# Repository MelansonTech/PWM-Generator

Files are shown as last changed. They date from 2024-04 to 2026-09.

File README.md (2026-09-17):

# PWM Generator

A low-cost, adjustable PWM signal generator built around an LM393 dual comparator.
One half of the comparator runs a sawtooth oscillator, the other slices it against an
adjustable threshold, and a discrete push-pull follower drives the output to 100 mA.

No microcontroller, no firmware — two trimmers and a jumper.

Complete CircuitStudio design: schematic, PCB, and a released manufacturing package
(Gerbers, NC drill, pick & place, BOM, STEP).

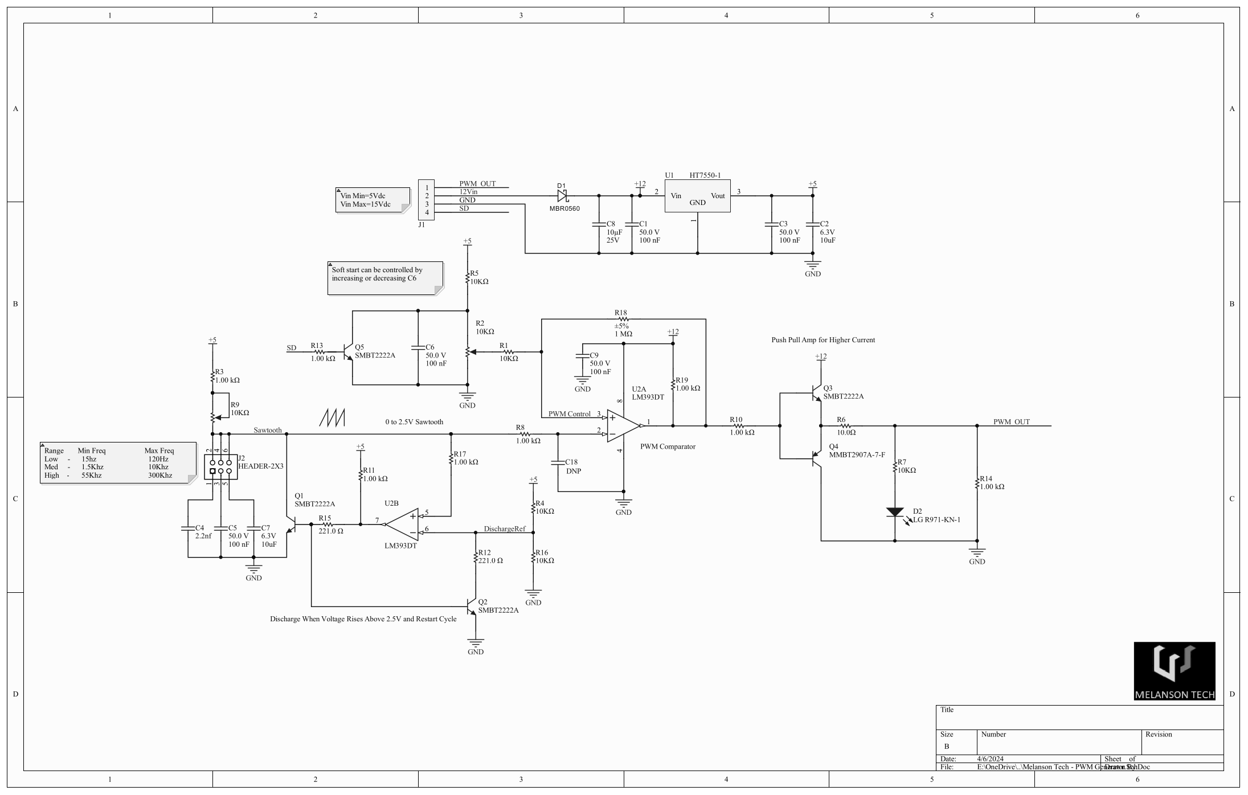
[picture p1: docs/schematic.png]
Schematic of the LM393 PWM generator


<sub>Full-size schematic, PCB drawings and 3D views:
[`PWM Generator Rev 1.PDF`](Default%20Configuration/Outputs/PWM%20Generator%20Rev%201.PDF)</sub>

---

## Specifications

| | |
|---|---|
| Supply voltage | 5 – 15 V DC |
| Output current | up to 100 mA |
| Output swing | GND to the input rail, less the input diode drop and one V<sub>BE</sub> |
| Duty cycle | 0 – 100 %, set by trimmer R2 |
| Frequency | 15 Hz – 300 kHz across three jumper-selected ranges |
| Soft start | duty ramps up from zero on power-up (C6) |
| Shutdown | active-high SD input forces 0 % duty |
| Board | 25.0 × 28.0 mm (0.98 × 1.10 in), 2-layer |
| Assembly | SMD on the bottom side only, plus 4 through-hole parts |
| Placements | 40 (19 unique parts, C18 not populated) |

## Frequency ranges

Range is selected by jumpering one pair on **J2**, which switches the oscillator's
timing capacitor:

| J2 jumper | Timing cap | Range |
|---|---|---|
| 1 – 2 | C4, 2.2 nF | 55 kHz – 300 kHz |
| 3 – 4 | C5, 100 nF | 1.5 kHz – 10 kHz |
| 5 – 6 | C7, 10 µF | 15 Hz – 120 Hz |

Within a range, **R9** sets the frequency. Exactly one pair should be jumpered at a time.

## Connections

**J1** — 1×4, 0.1 in pitch:

| Pin | Net | Description |
|---|---|---|
| 1 | `PWM_OUT` | PWM output, up to 100 mA |
| 2 | `Vin` | 5 – 15 V DC supply |
| 3 | `GND` | Ground |
| 4 | `SD` | Shutdown, active high — forces 0 % duty. Leave open or tie to GND for normal operation |

## Adjustments

| Part | Function |
|---|---|
| R9 | Frequency, within the range selected by J2 |
| R2 | Duty cycle |
| C6 | Soft-start time constant — increase for a slower ramp, decrease for a faster one |

Both are 10 kΩ top-adjust trimmers (CT94EW103).

## How it works

- **Input** — Vin enters through D1 (MBR0560 Schottky) for reverse-polarity protection.
  U1, an HT7550-1 SOT-89 LDO, derives the +5 V rail that the comparator and timing
  network run from. The output stage runs from the input rail, not the 5 V rail, so the
  PWM output swings as high as the supply allows.
- **Sawtooth oscillator** — One half of U2 (LM393) charges the selected timing capacitor
  through R9 and discharges it at a fixed reference, producing a 0 – 2.5 V sawtooth.
  J2 picks the capacitor and therefore the range; R9 sets the charge current and
  therefore the frequency.
- **PWM comparator** — The other half of U2 compares the sawtooth against a DC control
  voltage from R2. Where the control voltage sits within the sawtooth's 0 – 2.5 V span
  is the duty cycle.
- **Soft start** — C6 sits on the control node and charges through R5 at power-up, so
  the control voltage ramps from 0 V and the duty cycle ramps with it.
- **Shutdown** — Driving SD high turns on Q5, which pulls the control node to ground and
  holds the output at 0 % duty.
- **Output stage** — Q3 (NPN, SMBT2222A) and Q4 (PNP, MMBT2907A) form a complementary
  emitter follower. R6 (10 Ω) is in series with the output and R14 (1 kΩ) pulls it down.
- **Indicator** — D2, a green LED, sits across the output through R7 (10 kΩ), so its
  brightness follows the duty cycle.

Key parts: **U2** LM393DT · **U1** HT7550-1 · **Q1–Q3, Q5** SMBT2222A · **Q4** MMBT2907A-7-F · **D1** MBR0560

## Repository layout

```
Melanson Tech - PWM Generator.PrjPcb      CircuitStudio project
Melanson Tech - PWM Generator.SchDoc      Schematic
Melanson Tech - PWM Generator.CSPcbDoc    PCB layout
PWM Generator Rev 1.OutJob                Output job - regenerates everything below

docs/schematic.png                        Schematic image used above

Default Configuration/Outputs/
  PWM Generator Rev 1.PDF                 Schematic and PCB drawings
  Gerber/                                 RS-274X, 2 layers, bottom-side assembly
  NC Drill/                               Excellon drill files and drill report
  Pick Place/                             Placement data, .csv and .txt
  BOM/                                    Bill of materials with Digi-Key part numbers
  ExportSTEP/                             3D model of the assembled board
```

## Opening the design

Open `Melanson Tech - PWM Generator.PrjPcb` in Altium CircuitStudio (the outputs here
were generated with 1.5.2) or in Altium Designer, which reads the same formats.

The project's library search path points at a local folder, so schematic symbols and
footprints may not resolve on another machine. The design files themselves carry
everything needed to view, plot, and fabricate the board — the libraries are only
required to edit components or re-run an ECO.

## Ordering boards

The manufacturing package under `Default Configuration/Outputs/` was generated on
2024-04-06 and is what you send to a fab house:

- **Gerbers** — RS-274X, metric, 2 layers (`.GTL` top copper, `.GBL` bottom copper),
  with `.Outline` as the board outline
- **Drill** — `.DRL` (Excellon) plus `.DRR`; 40 plated holes, 4 tools, smallest 0.3 mm
- **Assembly** — pick & place plus the `.GBP` bottom paste layer. Every SMD part is on
  the bottom side, so this is a single-sided reflow. J1, J2 and the two trimmers are
  through-hole.
- **BOM** — `BOM_PartType-Melanson Tech - PWM Generator.xls`, with Digi-Key part numbers
  for most line items. C18 is marked **DNP** — do not populate.

If you change the design, re-run `PWM Generator Rev 1.OutJob` rather than editing these
files by hand.

## License

**CERN Open Hardware Licence Version 2 — Strongly Reciprocal (`CERN-OHL-S-2.0`).**

Copyright © 2024–2026 MelansonTech (Shawn Melanson).

This source describes Open Hardware and is licensed under CERN-OHL-S v2. You may redistribute
and modify it under the terms of that licence. This source is distributed *WITHOUT ANY EXPRESS
OR IMPLIED WARRANTY, INCLUDING OF MERCHANTABILITY, SATISFACTORY QUALITY AND FITNESS FOR A
PARTICULAR PURPOSE.* Please see the licence for applicable conditions.

In short: you may build, modify and sell this design, but if you distribute a modified version —
or a product made from one — you must publish your modified source under the same licence.

The full licence text is in [`LICENSE`](LICENSE), or at <https://cern.ch/cern-ohl>.

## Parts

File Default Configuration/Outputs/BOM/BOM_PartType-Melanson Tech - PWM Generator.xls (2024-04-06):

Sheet: BOM Report
Bill of Materials |  |  | <Parameter Title not found>
Source Data From: |  | Melanson Tech - PWM Generator.PrjPcb
Project: |  | Melanson Tech - PWM Generator.PrjPcb
Variant: |  | None
Creation Date: | 4/5/2024 | 2:28:50 PM
Print Date: | 2024-04-06 | 10:28:01
Production Quantity: | 100
Currency | CAD
Footprint | Comment | LibRef | Designator | Description | Quantity | Supplier 1 | Supplier Part Number 1 | Supplier Unit Price 1 | Supplier Order Qty 1 | Supplier Subtotal 1 | Manufacturer 1 | Manufacturer Part Number 1
Cap,0805 | 08055C104JAT2A | Cap,0805,100nf,50V,5%,08055C104JAT2A | C1, C3, C5, C6, C9 | 100nf 0805 Capacitor | 5 | Digi-Key | 478-3352-1-ND |  |  |  | Loading... | Loading...
Cap,0805 | CL21A106KQFNNNG | Cap,0805,10uf,6.3V,10%,CL21A106KQFNNNG | C2, C7 | CL21 Series 10 uF 6.3V ±10 % Tolerance X5R SMT Multilayer Ceramic Capacitor | 2 | Digi-Key | 1276-6457-1-ND | 0.04235 | 200 | $8.47 | Samsung | CL21A106KQFNNNG
CAP, 0805, HD | 2.2nf | CAP,0805,Generic | C4 | 2.2nf 0805 Capacitor | 1
Cap, 1206 | C3216X7R1E106K160AB | CAP,1206,10uF,25V,C3216X7R1E106K160AB | C8 | 10µF ±10% 25V Ceramic Capacitor X7R 1206 (3216 Metric) | 1 | Digi-Key | 445-7705-1-ND |  |  |  | Loading... | Loading...
CAP, 0805, HD | GRM21A5C2E101JW01D | Cap,0805,100pf,250V,5%,GRM21A5C2E101JW01D | C18 | CAP CER 100PF 250V 5% NP0 0805 | DNP | Digi-Key | 490-5542-1-ND | 0.13403 | 100 | $13.40 | Murata | GRM21A5C2E101JW01D
SOD123 | MBR0560 | Diode,SOD123,Shottky,60V,0.5A,MBR0560 | D1 | Dio,Sig,Schtky,0.5A,60V,SOD123 | 1 | Digi-Key | MBR0560TPMSCT-ND | 0.11076 | 100 | $11.08 | MCC | MBR0560-TP
LED,0805 | LG R971-KN-1 | LED,0805, Green,SMD,LG R971-KN-1 | D2 | LED GREEN DIFFUSED 0805 SMD | 1 | Digi-Key | 475-1410-1-ND |  |  |  | Loading... | Loading...
Header,4POS,0.1",Vert | Generic Header | Header 1x4,0.1",TH,Generic | J1 | Generic Header 4 pos header 0.1" | 1
HEADER-2X3 | HEADER-2X3 | HEADER-2X3 | J2 | 'Generic Header 8 pos 2x3 0.1" | 1
SOT23-3 | SMBT2222A | Trans,40V,600mA,0.33W, SMBT2222A | Q1, Q2, Q3, Q5 | NPN Silicon Switching Transistor, 40 V VCEO, 600 mA IC, SOT23, Reel, Green | 4 | Digi-Key | SMBT2222AE6327HTSA1CT-ND | 0.14739 | 400 | $58.95 | Infineon | SMBT2222AE-6327
SOT23-3 | MMBT2907A-7-F | Trans,PNP,60Vdc,600mA,SOT-23-3,MMBT2907A-7-F | Q4 | TRANS PNP 60V 0.6A SOT23-3 | 1 | Digi-Key | MMBT2907A-FDICT-ND | 0.06854 | 100 | $6.85 | Diodes Zetex | MMBT2907A-7-F
res, 0805, HD | Vishay / Dale CRCW080510K0FKTA | Res,0805,10.0kO,1%,100 ppm,CRCW080510K0FKTA | R1, R4, R5, R7, R16 | RES SMD 10K OHM 1% 1/8W 0805 | 5 | Digi-Key | 541-3016-1-ND |  |  |  | Loading... | Loading...
Res,TH,POT,TopAdj | CT94EW103 | Res,POT,TH,10KO,0.5W,±10%,±100ppm/°C,CT94EW103 | R2, R9 | TRIMMER 10K OHM 0.5W PC PIN TOP | 2 | Digi-Key | CT94EW103-ND |  |  |  | Loading... | Loading...
res, 0805, HD | Vishay CRCW08051K00JNEA | Res,0805,1.00 kO,5%,200ppm,CRCW08051K00JNEA | R3, R8, R10, R11, R13, R14, R17, R19 | Res Thick Film 0805 1K Ohm 5% 0.125W(1/8W) ±200ppm/C Molded SMD Automotive Paper T/R | 8 | Digi-Key | 541-1.0KADKR-ND |  |  |  | Loading... | Loading...
res, 0805, HD | RMCF0805JT10R0 | Res,0805,10.0O,5%,±200ppm/°C,RMCF0805JT10R0 | R6 | RES 10 OHM 5% 1/8W 0805 | 1 | Digi-Key | RMCF0805JT10R0CT-ND | 0.01106 | 100 | $1.11 | Stackpole Electronics | RMCF0805JT10R0
res, 0805, HD | Vishay Dale CRCW0805221RFKTA | Res,0805,221O,1%,100ppm,CRCW0805221RFKTA | R12, R15 | RES SMD 221 OHM 1% 1/8W 0805 | 2 | Digi-Key | 541-221CCT-ND | 0.02671 | 200 | $5.34 | Vishay | CRCW0805221RFKEA
res, 0805, HD | CR0805-JW-105ELF | Res,0805,1MegO,5%,200ppm,0805W8F1005T5E | R18 | RES SMD 1M OHM 5% 1/8W 0805 | 1 | Digi-Key | CR0805-JW-105ELFCT-ND |  |  |  | Loading... | Loading...
SOT89-3 | HT7550-1 | Reg,Linear,Fixed,SOT-89-3,30Vin,5Vout,150mA,HT7550-1 | U1 | LOW DROPOUT REGULATORS(LDO) POSITIVE FIXED 55MV @ 1MA 30V 5V 150MA SOT-89(SOT-89-3) ROHS | 1
SOIC-8 | LM393DT | OPAMP,DUAL,COMAPRATOR,SOIC8,OPEN-COLLECTOR,LM393DT | U2 | IC COMPARATOR LP DUAL 8-SOIC | 1 | Digi-Key | 497-1593-1-ND | 0.26311 | 100 | $26.31 | STMicroelectronics | LM393DT
 |  |  |  |  | 39 |  |  |  |  | $131.52
Approved |  | Notes

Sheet: Project Information
Project Full Path | E:\OneDrive\Shawn\circuitstudio projects\PWM Generator\Melanson Tech PWM Generator\Melanson Tech - PWM Generator.PrjPcb
Project Filename | Melanson Tech - PWM Generator.PrjPcb
Variant Name | None
Data-Source Filename | Melanson Tech - PWM Generator.PrjPcb
Data-Source Full Path | E:\OneDrive\Shawn\circuitstudio projects\PWM Generator\Melanson Tech PWM Generator\Melanson Tech - PWM Generator.PrjPcb
Title | <Parameter Title not found>
Total Quantity | 40
Report Time | 2:28:50 PM
Report Date | 4/5/2024
Report Date & Tine | 4/5/2024 2:28:50 PM
Output Name | BOM_PartType
Output Type | BOM_PartType
Output Generator Name | BOM
Output Generator Description | Bill of Materials

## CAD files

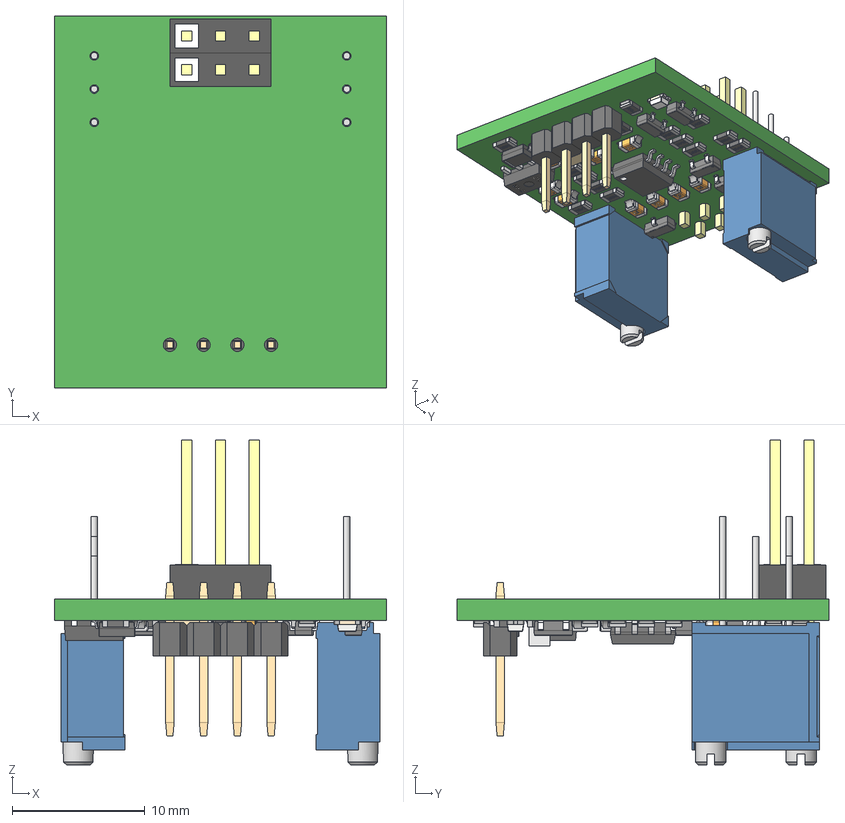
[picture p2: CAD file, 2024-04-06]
Default Configuration/Outputs/ExportSTEP/Melanson Tech - PWM Generator.step
25.0 x 28.0 x 24.4 mm
Board
0805_Resistor_v11 x 17
User_Library-0805_Cap x 9
pin
pin(Mirror)
icbody
Header,_Male,_2.54mm,_1x4
Extruded x 13
SOT23-3 x 5
_CT-94-94EW_body x 2
_CT-9-Dial_dial x 2
User_Library-SOIC-8-1
0805_Chip_SMD_LED_(2x1.2mm)_v1

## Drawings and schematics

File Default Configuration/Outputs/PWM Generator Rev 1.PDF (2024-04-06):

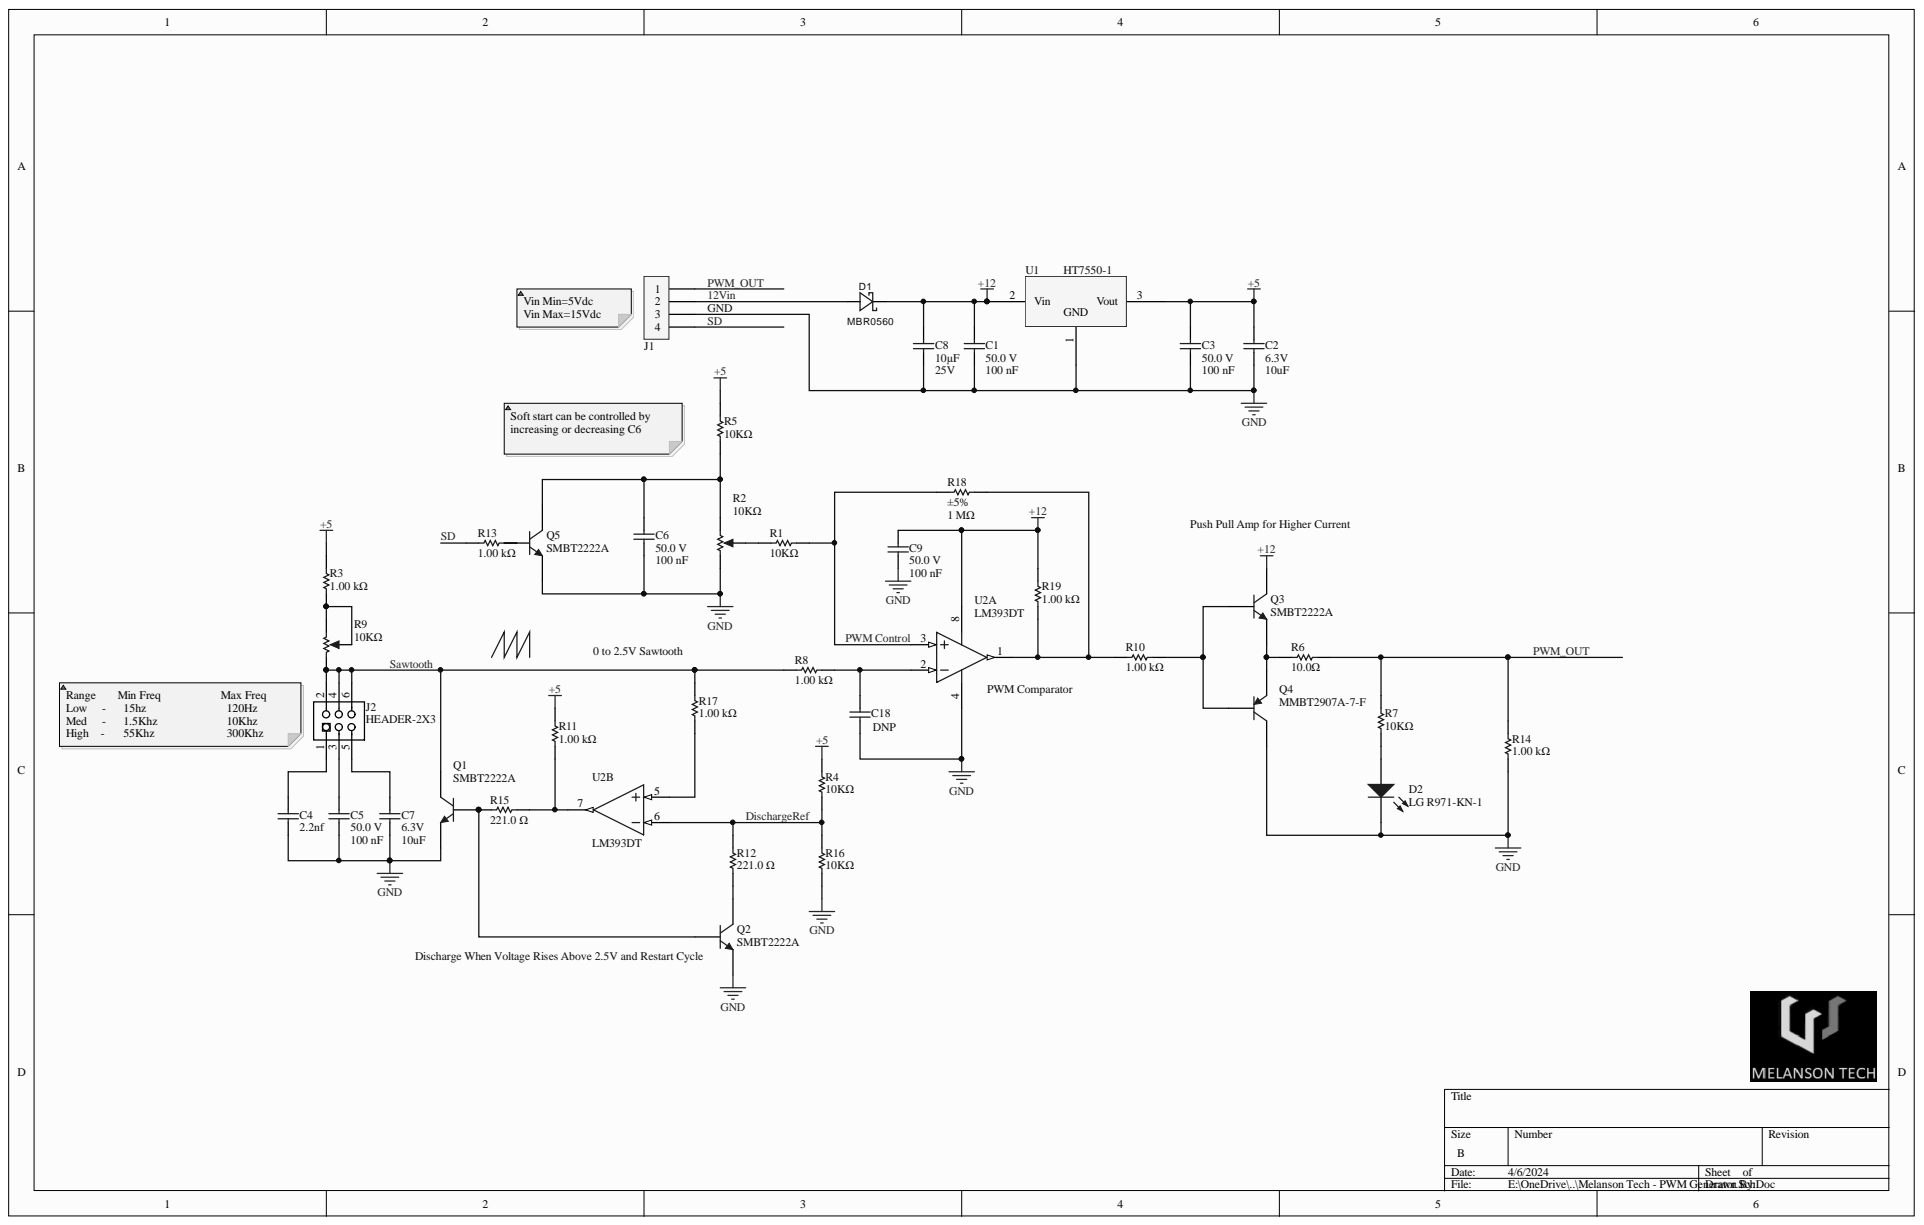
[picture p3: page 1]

M Gener Drawatorn B.SchDy: oc

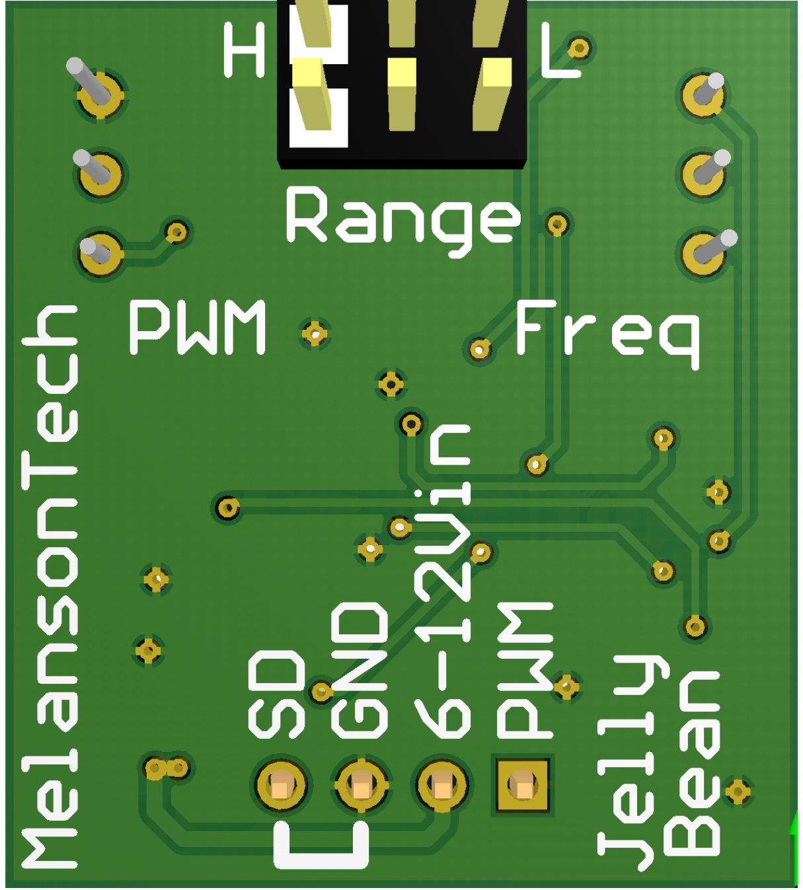
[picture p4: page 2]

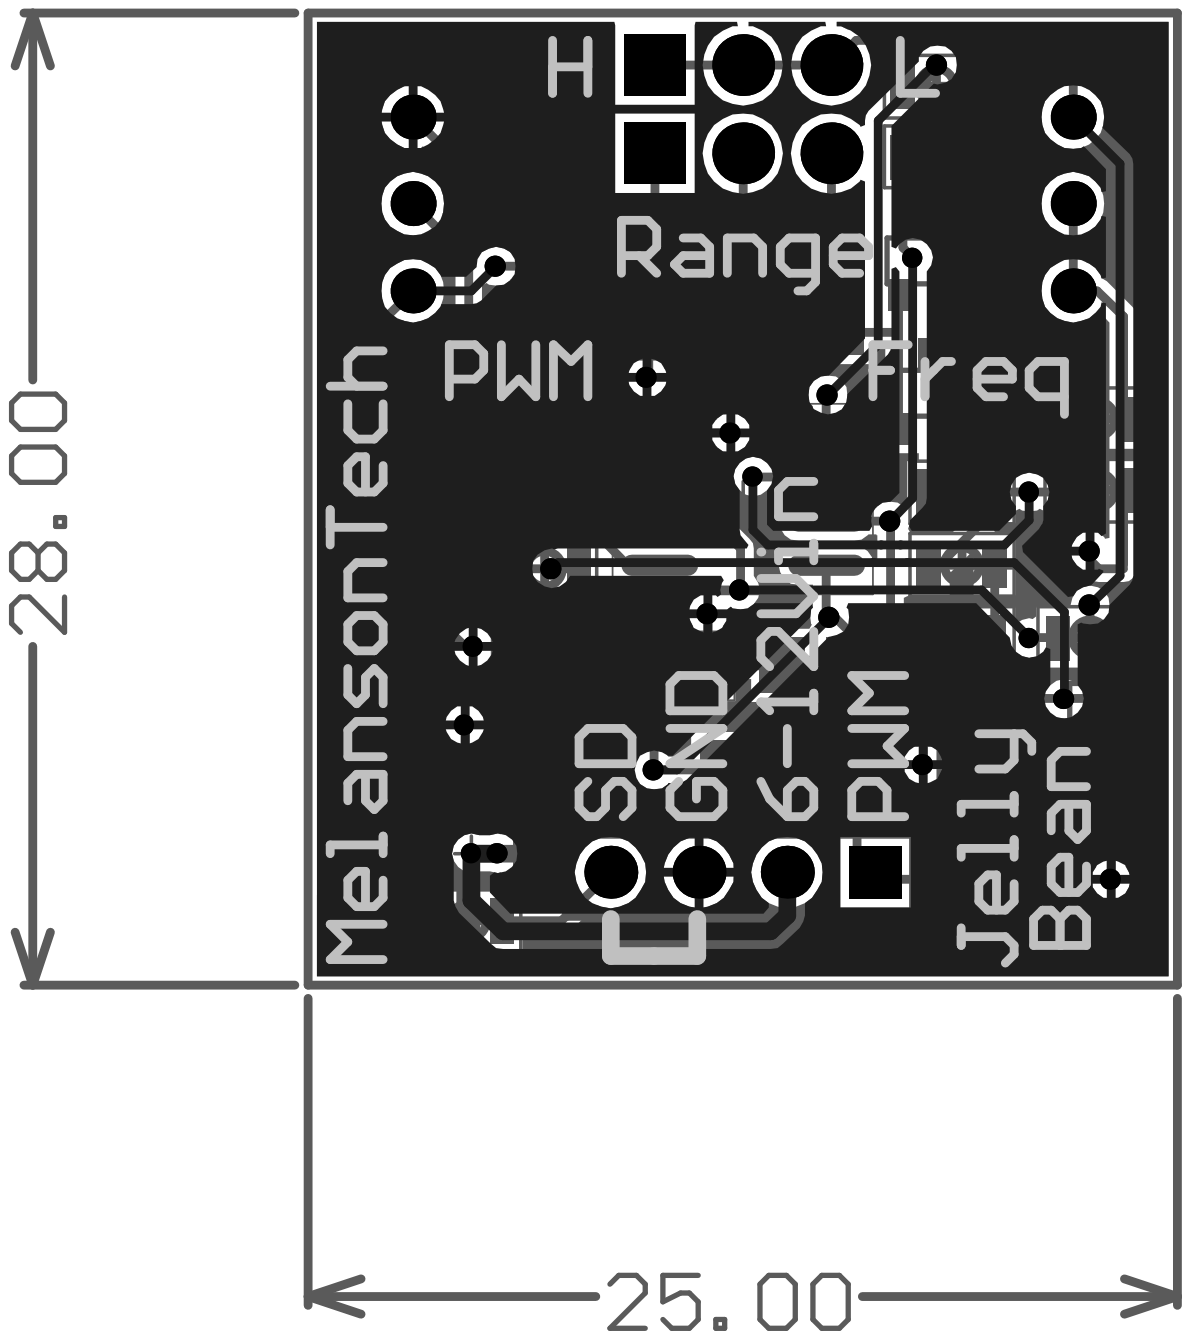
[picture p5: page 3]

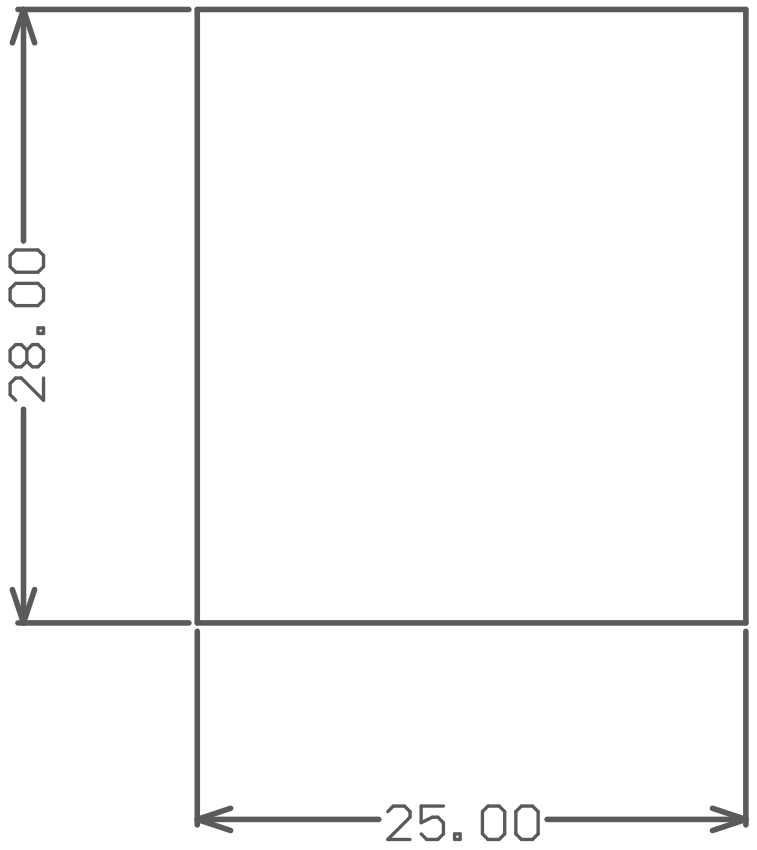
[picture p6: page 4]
PAJ202 PAJ204 PAJ206; PAJ201 PAJ203 PAJ205 COJ2 PAJ202 PAJ204 PAJ206

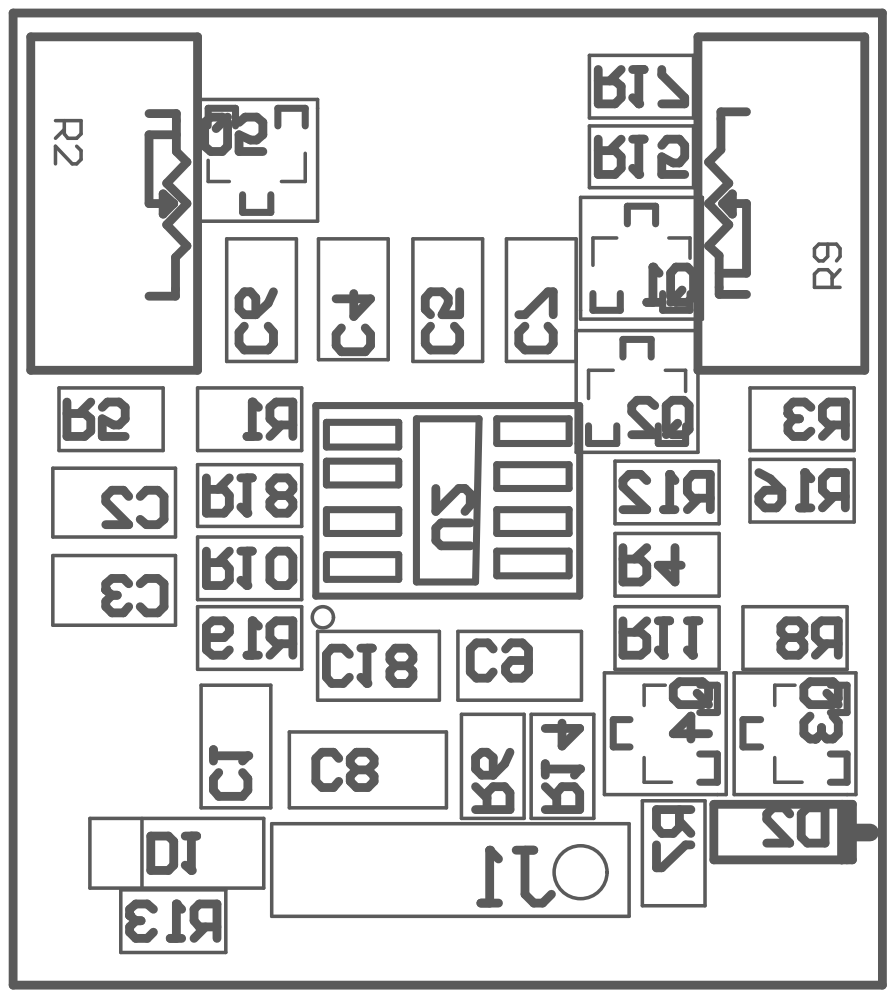
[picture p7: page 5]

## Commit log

2026-09-14 Restore the OutJob to the repo and fix the project's reference to it
    The project pointed at ..\PWM Generator Rev 1\PWM Generator Rev 1.OutJob,
    a path outside the repository, so a fresh clone had no way to regenerate the
    Gerbers, drill files, BOM or STEP export. The OutJob itself was only present
    as a backup inside History/.
    Recovered it from History/3F35F39F/PWM Generator Rev 1.~(2).OutJob.Zip (saved
    2024-04-05) and placed it beside the project, which is where [Configuration1]
    OutputJobFileName1 already expected to find it. Three keys held absolute paths
    into a local drive - one at the SchDoc that now sits next to it, two at an
    older baseline project's output folder - and were blanked to ma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
    [Melanson Tech - PWM Generator.PrjPcb]
2026-09-14 Stop tracking CircuitStudio-generated files; add a .gitignore
    None of these are design sources - CircuitStudio rewrites them on its own, and
    several only describe the machine they were generated on.
    History/ 1.8 MB of local backup snapshots
    Logs/ an ECO log from 2024-04-06
    *.OutputStatus per-output run state, six files, each listing local
    absolute paths under E:\OneDrive\Shawn\...
    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
2026-09-14 Rewrite the README as documentation for the board
    The previous text was a nine-heading project narrative - overview, challenges,
    impact, conclusion - that never said how to use the thing. Replaced with what
    someone landing on the repo actually needs: specs, the J2 range table, the J1
    pinout, what each trimmer does, how the circuit works, where the files are, and
    what to send a fab house.
    Details were read back out of the design rather than restated from the old
    prose, so a few things are now right that were not:
    - low range is 15 Hz - 120 Hz, matching the table on the schematic; the old
    text said 100 Hz
    - the three ranges are named against the capacitor each J2 pair selects
    (C4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
2026-09-16 Relicense under CERN-OHL-S v2
    Matches Melanson-Tech-Isolated-Shunt-Amplifier, which already ships the CERN
    Open Hardware Licence v2 Strongly Reciprocal. Licence text copied verbatim from
    that repository so the two stay identical, and the README notice mirrors its
    wording.
    MIT is a software licence - it grants rights over source code, and says nothing
    useful about a board someone fabricates from these Gerbers. CERN-OHL-S covers
    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
2026-09-16 Put the schematic on the front page
    Rendered from page 1 of the release PDF at 200 dpi and trimmed to the drawing
    frame - the sheet is letter-size with about 20% of its height empty above and
    below the border.
    Reading the render also settled what D2 is for. R7 and the LED hang off the
    output node after R6, not off the supply rail, so the LED tracks duty cycle
    rather than just showing that the board is powered. Added that to "How it
    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
